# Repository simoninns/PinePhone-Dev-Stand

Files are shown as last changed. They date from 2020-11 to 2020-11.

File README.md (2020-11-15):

# PinePhone Development Stand
The PinePhone development stand is specifically designed for the PinePhone with software development and testing in mind.  The phone is held securely at a comfortable angle (for viewing and use of the touch screen) and will not tip over if the phone is used at the bottom or top of the screen.  In addition, the bracket has side supports to prevent the phone falling sideways when the power or volume buttons are used.  The lower edge of the phone is raised around 6cm by the stand to ensure that all types of USB-C cables and connectors can fit easily without stressing the socket or cable.  The base of the stand has indented guides for stick-on rubber feet (such as 3M Bumpon feet) which can be used to prevent the stand from sliding on the desk when pressing on the touch screen.

Note: This project is GPLv3 open-source. The github repository for the model (containing the complete OpenSCAD project) can be found at https://github.com/simoninns/PinePhone-Dev-Stand

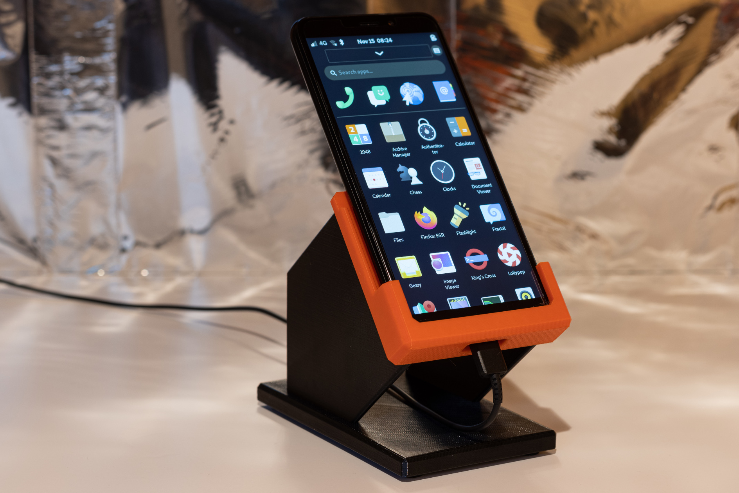
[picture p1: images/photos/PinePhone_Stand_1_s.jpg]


# Overview

The case is designed in two parts (the stand and the bracket) which slot together.  This also allows a simple two colour print if desired (or both parts can be printed at the same time).

The project also includes a simple model of the PinePhone to assist with modelling and adjustments.

# Assembly instructions

Print both parts of the stand.  Run a small amount of super-glue into both recesses on the back of the phone bracket.  The press this into the stand (ensuring that the bracket and stand are the right way up).  Use a little pressure to hold in place for 30 seconds or until the glue is correctly set.

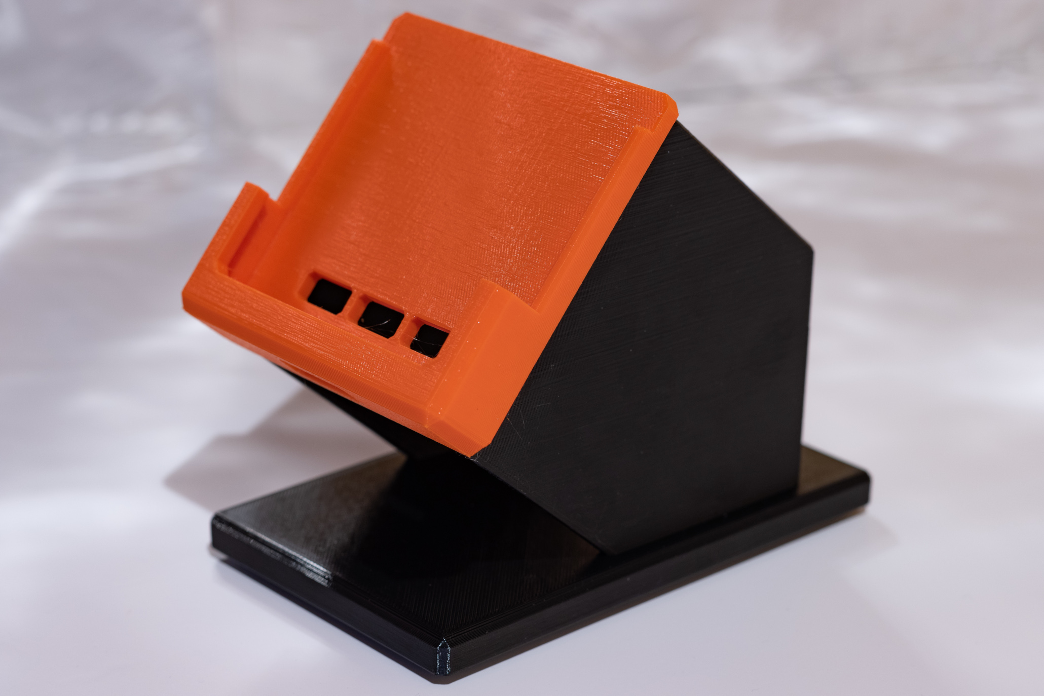
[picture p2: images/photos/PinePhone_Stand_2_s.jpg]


Guides are provided on the unside of the base for 13-14mm rubber feet (use 3M bumpon or similar).  Either 4 or 6 feet can be used depending on the desired level of stability.

# Printing instructions

## Overview

The model has been printed and tested on the Prusa MK3S/MMU2S printer using PETG filament. All parts fit on a 20x20 printing bed.

The OpenSCAD source files provide a parameter interface that allows you to render either the whole model or the individual parts (ready for STL (or other 3D format) export).  This requires OpenSCAD 2019.05 or later.

The base can be printed as-is on the print bed as the side parts do not need any support.  Print the bracket with the USB-C hole on the print bed.  No support is necessary for the bracket either.  All edges are angled (rather than rounded) to ensure simple slicing and printing of the shapes.

## Recommended print settings
### Stand
* Number required: 1
* Material: Prusament PETG (Prusa Jet Black)
* Layer: 0.20mm (Quality)
* Infill: 15%
* Supports: None
* Print time (approximate): 6h 41m

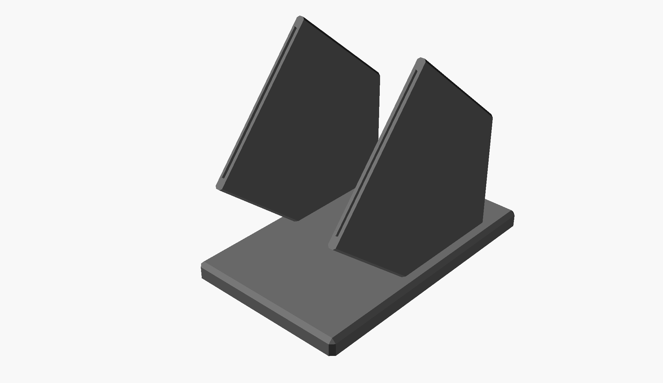
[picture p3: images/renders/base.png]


### Phone bracket
* Number required: 1
* Material: Prusament PETG (Prusa Orange)
* Layer: 0.20mm (Quality)
* Infill: 15%
* Supports: None
* Print time (approximate): 3h 26m

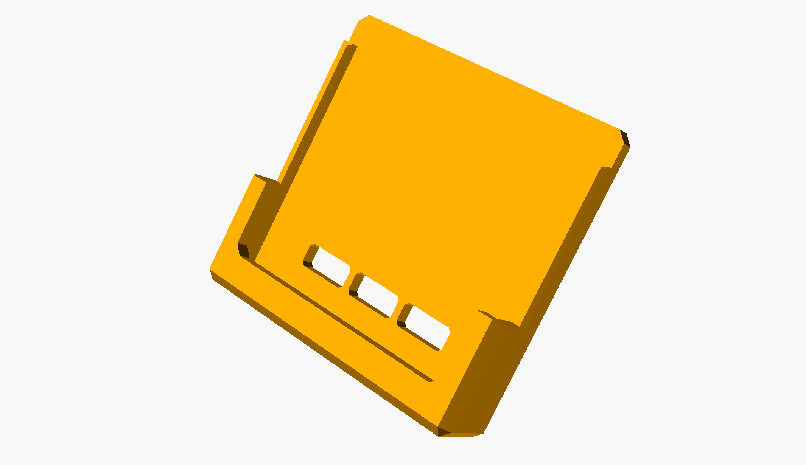
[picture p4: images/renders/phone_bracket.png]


# Author

The PinePhone development stand is designed and maintained by Simon Inns.

# Licensing

## OpenSCAD source files - software license (GPLv3)

    This is free software: you can redistribute it and/or modify
    it under the terms of the GNU General Public License as published by
    the Free Software Foundation, either version 3 of the License, or
    (at your option) any later version.
    
    This program is distributed in the hope that it will be useful,
    but WITHOUT ANY WARRANTY; without even the implied warranty of
    MERCHANTABILITY or FITNESS FOR A PARTICULAR PURPOSE.  See the
    GNU General Public License for more details.
    
    You should have received a copy of the GNU General Public License
    along with this program.  If not, see <http://www.gnu.org/licenses/>.

## 3D model files - Creative Commons license (Creative Commons BY-SA 4.0)

Please see the following link for details: https://creativecommons.org/licenses/by-sa/4.0/

You are free to:

Share - copy and redistribute the material in any medium or format
Adapt - remix, transform, and build upon the material
for any purpose, even commercially.

This license is acceptable for Free Cultural Works.

The licensor cannot revoke these freedoms as long as you follow the license terms.

Under the following terms:

Attribution - You must give appropriate credit, provide a link to the license, and indicate if changes were made. You may do so in any reasonable manner, but not in any way that suggests the licensor endorses you or your use.

ShareAlike - If you remix, transform, or build upon the material, you must distribute your contributions under the same license as the original.

No additional restrictions - You may not apply legal terms or technological measures that legally restrict others from doing anything the license permits.

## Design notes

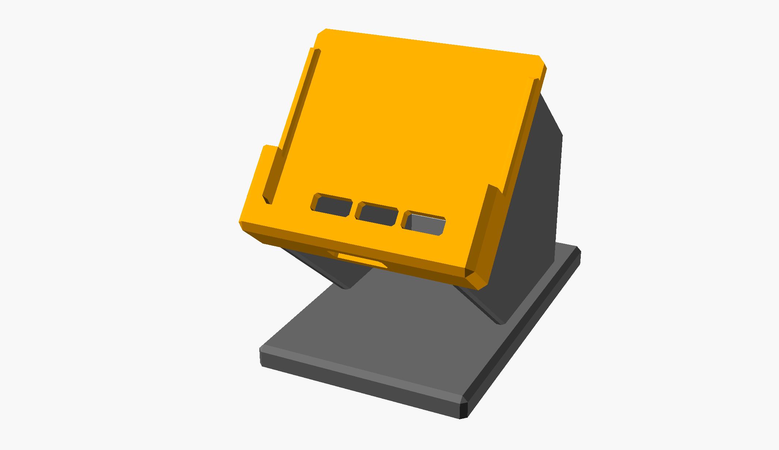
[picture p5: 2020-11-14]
images/renders/complete.png

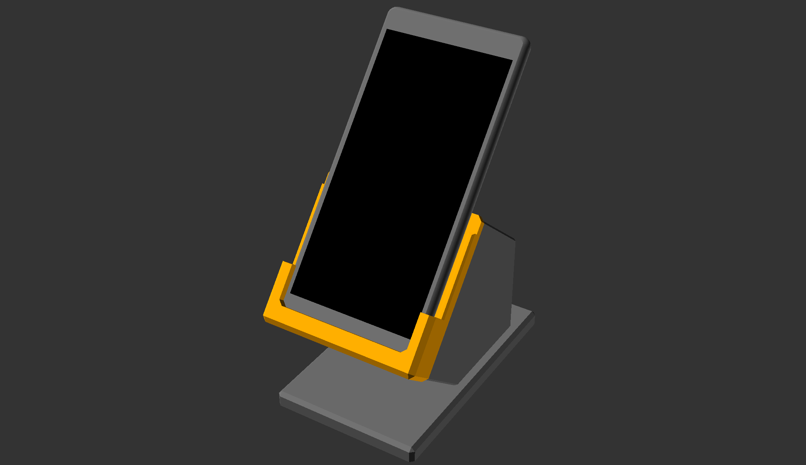
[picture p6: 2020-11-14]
images/renders/complete_with_phone.png

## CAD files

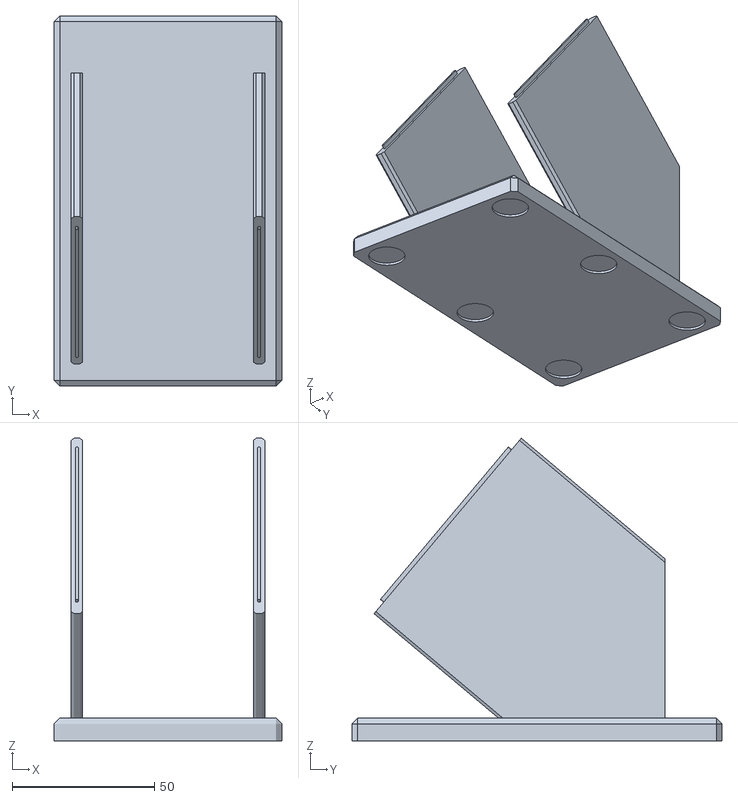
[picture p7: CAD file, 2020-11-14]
stl/base.stl
80.0 x 130.0 x 106.3

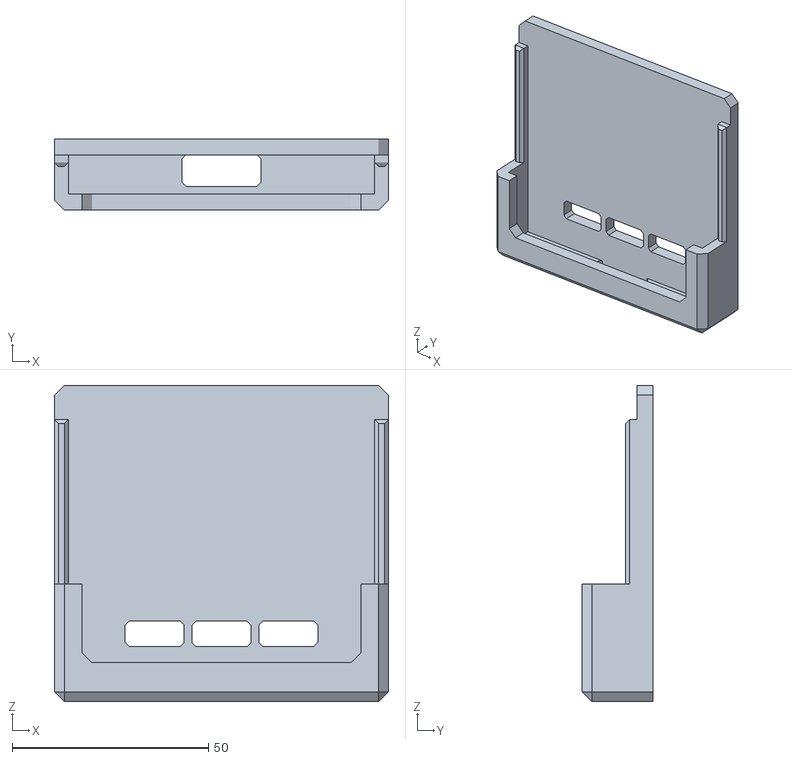
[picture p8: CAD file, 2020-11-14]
stl/bracket.stl
85.0 x 18.0 x 80.5

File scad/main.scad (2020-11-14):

/************************************************************************

	main.scad
    
    PinePhone Dev Stand
    Copyright (C) 2020 Simon Inns
    
    This is free software: you can redistribute it and/or modify
	it under the terms of the GNU General Public License as published by
	the Free Software Foundation, either version 3 of the License, or
	(at your option) any later version.
    
    This program is distributed in the hope that it will be useful,
    but WITHOUT ANY WARRANTY; without even the implied warranty of
    MERCHANTABILITY or FITNESS FOR A PARTICULAR PURPOSE.  See the
    GNU General Public License for more details.
    
    You should have received a copy of the GNU General Public License
    along with this program.  If not, see <http://www.gnu.org/licenses/>.
	
    Email: simon.inns@gmail.com
    
************************************************************************/

include <BOSL/constants.scad>
use <BOSL/transforms.scad>
use <BOSL/shapes.scad>

// Rendering quality
$fn=50;

// Display assembled or ready for printing:
display_assembled = "Assembled"; // [Assembled, Printing]
display_base = "Yes"; // [Yes, No]
display_bracket = "Yes"; // [Yes, No]
display_phone = "Yes"; // [Yes, No]

// Render a mock up of the PinePhone
// Note: Front bezel shape is approximate at best
module phone()
{
    // Dimensions: 160.5 x 76.6 x 9.2 mm
    color("DimGray") difference() {
        // Phone body is 160.5 x 76.6 x 9.2 mm with 2.5mm radius edges
        cuboid([76.6,160.5,10], fillet=5);
        move([0,0,5.5 - 0.8]) cuboid([76.6,160.5,1]);

        // USB-C port is 9mm x 2.5mm - top of port is 4.5mm back from front of phone
        move([0,-80,3.25 - 4.5]) rotate([90,0,0]) cuboid([9, 2.5, 10], fillet=1, edges=EDGES_Z_ALL);

        // Screen is 68mm x 135mm - make cut-out
        move([0,0,3.7]) cuboid([68, 135, 2]);

        // Speaker is 11mm from base - make cut-out
        move([0, -67, -5]) cuboid([45, 4.5, 2]);
    }

    // Screen is 68mm x 135mm
    color("Black") move([0,0,3.7]) cuboid([68, 135, 1]);

    // Speaker is 11mm from base - make cut-out
    color("Black") move([0, -67, -4.5]) cuboid([45, 4.5, 1]);

    // Missing buttons
    // Missing camera
    // Missing headphone jack
}

// Render the phone bracket
module phoneBracket()
{
    difference() {
        move([0,-44,0]) cuboid([77 + 8,161 / 2,10 + 8], chamfer=2.5, edges=EDGES_Z_ALL+EDGES_TOP);

        cuboid([78,161,10]);
        move([0,-14,4]) cuboid([77 + 10,161 / 2,10 + 8]);
        move([0,-34,10]) cuboid([77 - 6,161 / 2,10 + 8], chamfer=2.5, edges=EDGES_Z_ALL);

        // USB-C cut out
        move([0,-80,-1]) cuboid([20,20,8], chamfer=1, edges=EDGES_Y_ALL);

        // Speaker cut out 45 + 2
        move([(45 / 3) + 2 ,-67, -7]) cuboid([45 / 3, 4.5 + 2, 10],  chamfer=1, edges=EDGES_Z_ALL);
        move([0,-67, -7]) cuboid([45 / 3, 4.5 + 2, 10],  chamfer=1, edges=EDGES_Z_ALL);
        move([-((45 / 3) + 2),-67, -7]) cuboid([45 / 3, 4.5 + 2, 10],  chamfer=1, edges=EDGES_Z_ALL);

        // Right joiner
        move([32,0,0]) {
            joiner(false);
        }

        // Left joiner
        move([-32,0,0]) {
            joiner(false);
        }
    }

    // Add some side stays to stop the phone rocking when the power button is pressed
    move([40.75,-35,-3.5]) cuboid([3.5,45,3], chamfer=1, edges=EDGES_TOP);
    move([-40.75,-35,-3.5]) cuboid([3.5,45,3], chamfer=1, edges=EDGES_TOP);
}

// Render a side of the stand
module standSide()
{
    difference() {
        move([0,-44,-84]) cuboid([4,80.5,150], chamfer=1, edges=EDGES_Z_ALL);
        rotate([90 - 50,0,0]) move([0,-20,-100]) cuboid([6,200,90]);
        rotate([90 - 50,0,0]) move([0, -154, 0]) cuboid([6,80,300]);
    }
}

// Joiners to align join between base and phone bracket
module joiner(direc)
{
    // Positive = true - Negative = false
    // Note: Negative is slighly larger to ensure easy fit
    move([0,-44,-7.5 - (1.5 / 2)]) {
        if (direc) cuboid([1,70,1.5], fillet=0.5, edges=EDGES_Z_ALL);
        if (!direc) cuboid([1.2,70,1.7], fillet=0.5, edges=EDGES_Z_ALL);
    }
}

// Render the base of the stand
module standBase()
{
    rotate([90 - 50,0,0]) move([0, -113 + 2, -10]) {
        difference() {
            cuboid([80,8,130], chamfer=2, edges=EDGES_Y_ALL+EDGES_BACK);

            // Recess for 3M feet
            rotate([90,0,0]) {
                // Centre feet
                move([30,0,5]) cyl(h=4, d=14);
                move([-30,0,5]) cyl(h=4, d=14);

                // Back feet
                move([30,-55,5]) cyl(h=4, d=14);
                move([-30,-55,5]) cyl(h=4, d=14);

                // Front feet
                move([30, 55,5]) cyl(h=4, d=14);
                move([-30, 55,5]) cyl(h=4, d=14);
            }
        }
    }

}

// Render the stand
module stand()
{
    // Right
    move([32,0,0]) {
        standSide();
        joiner(true);
    }

    // Left
    move([-32,0,0]) {
        standSide();
        joiner(true);
    }

    standBase();
}

// Render the complete model
module main()
{
    if (display_assembled == "Assembled") {
        move([0,0,55 + 60]) rotate([50,0,0]) {
            if (display_phone == "Yes") phone();
            if (display_bracket == "Yes") color("Orange") phoneBracket();
            if (display_base == "Yes") color("DimGray") stand();
        }
    }

    if (display_assembled == "Printing") {
        if (display_bracket == "Yes") {
            color("Orange") {
                rotate([90,0,0]) move([0,84.25,0]) phoneBracket();
            }
        }
        if (display_base == "Yes") {
            color("DimGray") {
                move([0,0,55 + 60]) rotate([50,0,0]) stand();
            }
        }
    }
}

main();
